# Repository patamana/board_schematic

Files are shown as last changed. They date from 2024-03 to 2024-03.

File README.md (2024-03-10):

# パタマナボード 回路図・kicadデータ
パタマナボードの回路図やkicadデータです。

## パタマナボードの概要
XIAO用キーボード基板です。<br>
XIAOは無線接続ができて便利ですが、端子数が少なく、マトリクス構造にしてもOLEDを制御するピンなどが足りなくなってしまいます。<br>
シフトレジスタの74HC165を4つ実装することで、**XIAOの3ピンで32キーの読み取りに対応**しました。<br>
I2CによるOLED制御、TRRSジャックによる左右通信、充電用のPHコネクタやスライドスイッチが実装可能です。

## シフトレジスタの概要
XIAOのD1,D2,D3ピンが74HC165のLD,CK,QHに配線されています。<br>
LDをLOWにすることでシフトレジスタにロードされ、<br>
QHからSW0のHIGE/LOWが出力されます。<br>
CKが立ち上がるたびに出力信号がSW1,SW2...とシフトされていきます。

## ピン配置
XIAOのSDA,SCLピンがOLED用の端子のSDA,SCLに配線されています。

TRRSにはXIAOのTX,RXピンとUSBからの5Vが配線されており、左右でTXとRXが逆になっているので、TRRSジャックの実装位置を変えることで、UARTでの左右通信が可能です。

XIAOの裏面の+端子をパタマナボード裏面のBAT+端子に繋げ、スライドスイッチとPHコネクタを実装し、PHコネクタにリチウムイオンポリマーバッテリーを繋げることで充電が可能です。

バッテリーの電圧を200kΩ抵抗2つの直列で分圧した電圧がXIAOのD0ピンに印加されているので、電圧値を読み取ることでバッテリー残量がわかります。

D8,D9,D10ピンは未使用なので、自由に利用できます<br><br>

詳しい利用方法は[patamana.com](https://patamana.com)を参照してください。

Arduino IDE を用いる場合は、[patamana/keybard_firmware/simple_split_keyboard](https://github.com/patamana/keyboard_firmware/tree/main/simple_split_keyboard)のコードを参考にしてください。

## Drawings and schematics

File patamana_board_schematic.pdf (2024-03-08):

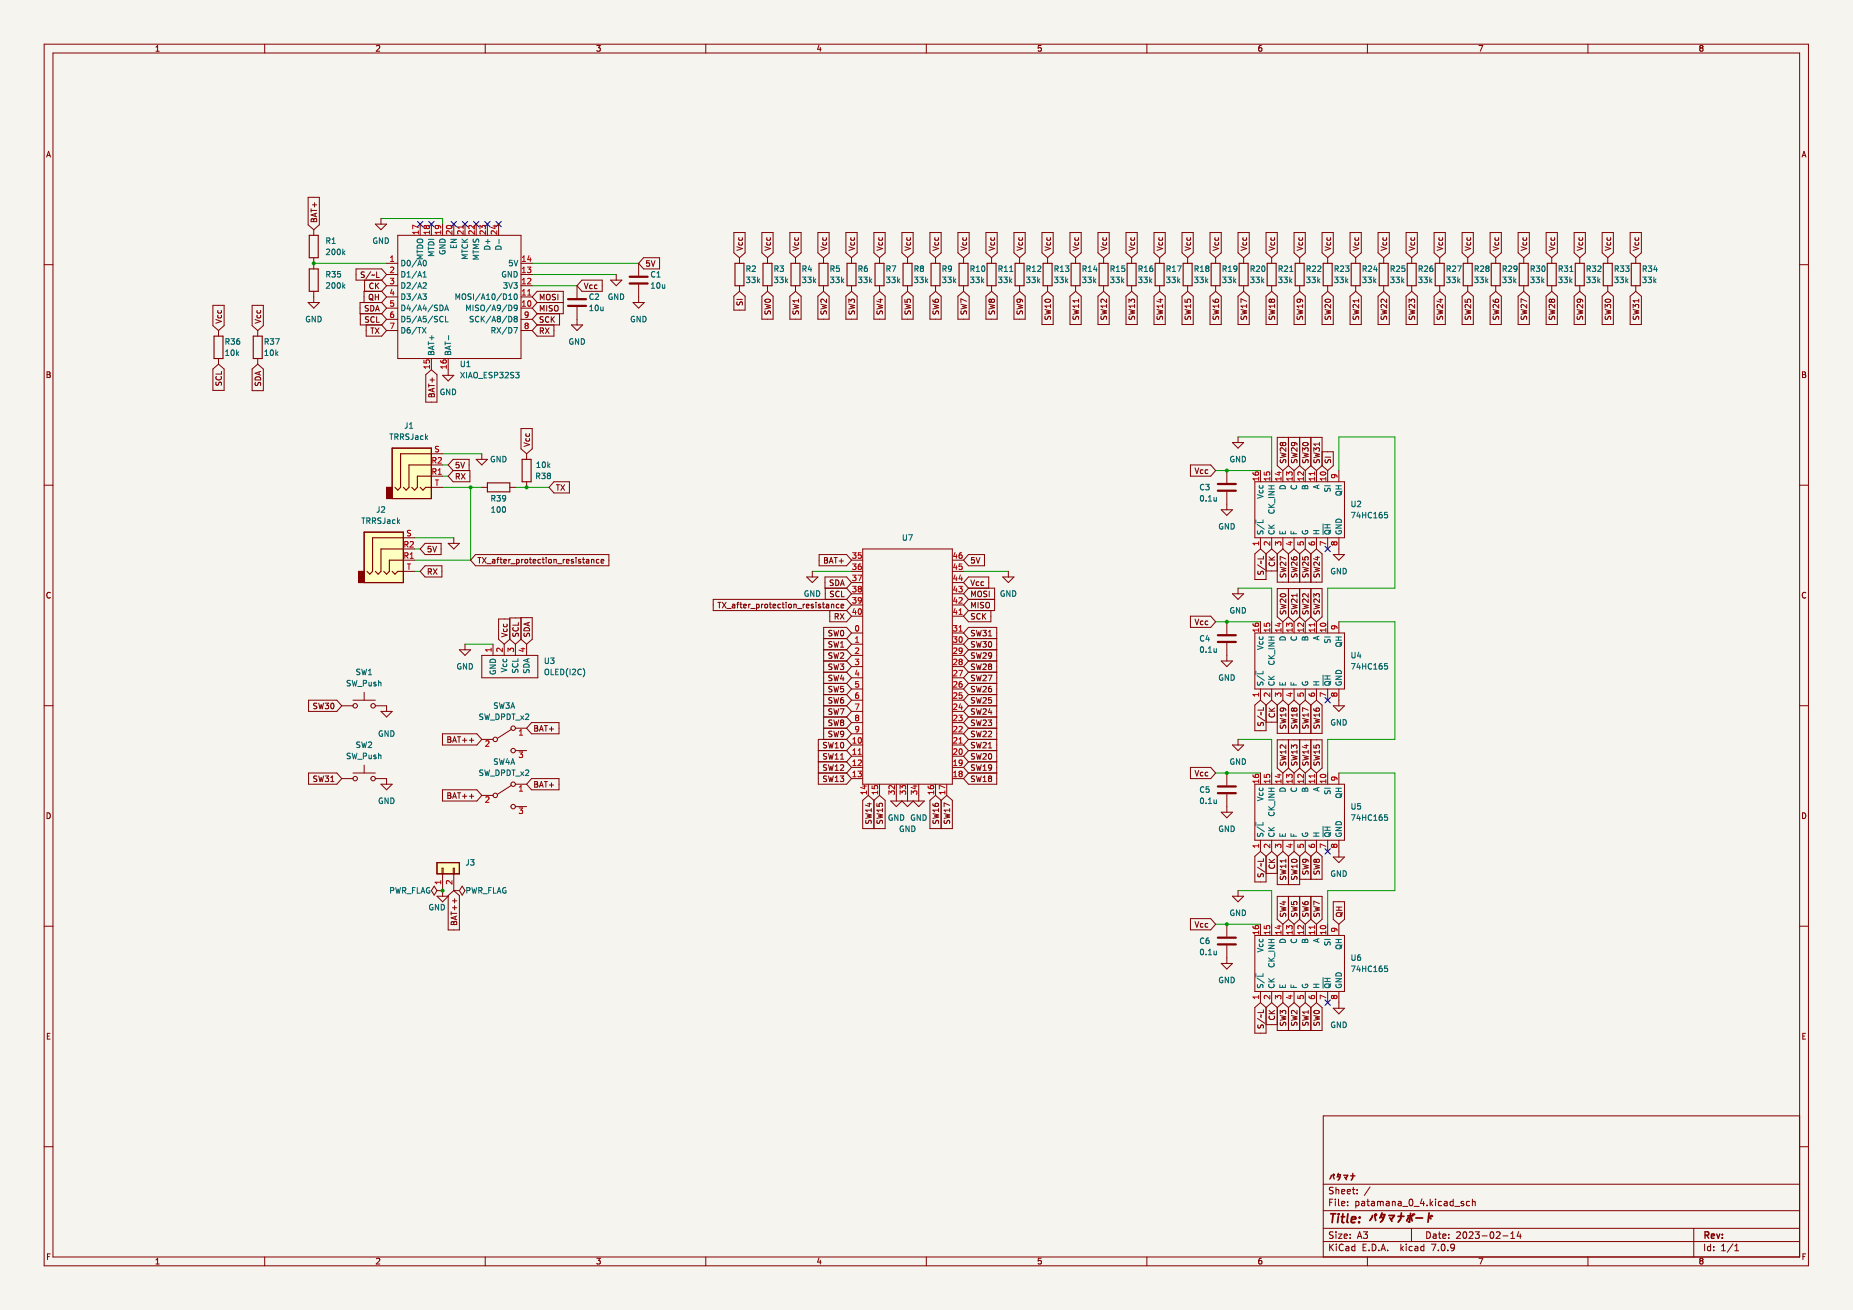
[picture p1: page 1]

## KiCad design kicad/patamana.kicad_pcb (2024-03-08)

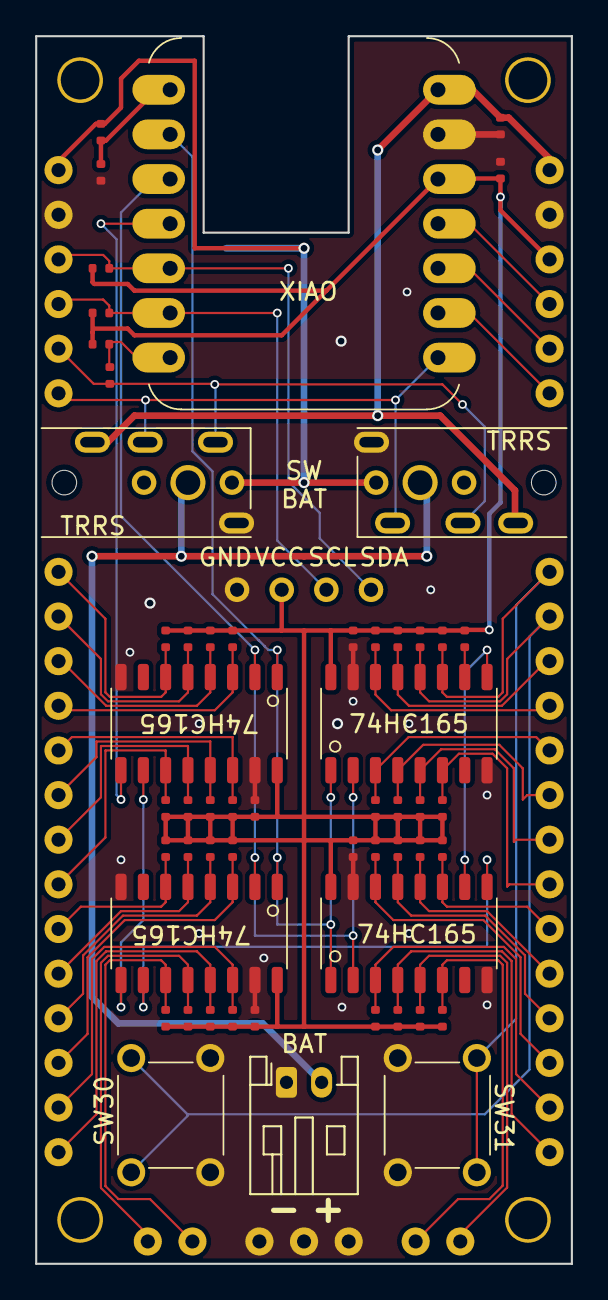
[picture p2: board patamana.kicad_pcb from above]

Board: 2 copper layers, 30.5 x 69.8 mm, 59 parts (0 on the bottom side), 53 nets.

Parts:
C1, C2: 10u; 0402
C3, C4, C5, C6: 0.1u; 0402
J1, J2: TRRSJack; MJ-4PP-9
J3: Conn_01x02; JST_PH_S2B-PH-K_1x02_P2.00mm_Horizontal
R1, R35: 200k; 0402
R2, R3, R4, R5, R6, R7, R8, R9, R10, R11, R12, R13, R14, R15, R16, R17, R18, R19, R20, R21, R22, R23, R24, R25, R26, R27, R28, R29, R30, R31, R32, R33, R34: 33k; 0402
R36, R37, R38: 10k; 0402
R39: 100; 0402
SW1, SW2: SW_Push; Tactile_Switch_TVDP01
SW3, SW4: SW_DPDT_x2; SS-12D00-G5
U1: XIAO_ESP32S3
U2, U4, U5, U6: 74HC165; SOT109-1_SO16
U3: OLED(I2C); OLED_128x64_I2C
U7: patamana_0_4_out

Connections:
5V: C1.1, J1.R2, J2.R2, U1.14 (5V), U7.46
BAT+: R1.1, SW3.1 (A), SW4.1 (A), U7.35
BAT++: J3.2, SW3.2 (B), SW4.2 (B)
CK: U1.3 (D2/A2), U2.2 (CK), U4.2 (CK), U5.2 (CK), U6.2 (CK)
GND: C1.2, C2.2, C3.2, C4.2, C5.2, C6.2, J1.S, J2.S, J3.1, R35.2, SW1.2, SW2.2, U1.13 (GND), U2.8 (GND), U2.15 (CK_INH), U3.1 (GND), U4.8 (GND), U4.15 (CK_INH), U5.8 (GND), U5.15 (CK_INH), U6.8 (GND), U6.15 (CK_INH), U7.32, U7.33, U7.34, U7.36, U7.45
MISO: U1.10 (MISO/A9/D9), U7.42
MOSI: U1.11 (MOSI/A10/D10), U7.43
unnamed: R1.2, R35.1, U1.1 (D0/A0)
unnamed: U2.9 (QH), U4.10 (SI)
unnamed: U4.9 (QH), U5.10 (SI)
unnamed: U5.9 (QH), U6.10 (SI)
QH: U1.4 (D3/A3), U6.9 (QH)
RX: J1.R1, J2.T, U1.8 (RX/D7), U7.40
SCK: U1.9 (SCK/A8/D8), U7.41
SCL: R36.2, U1.6 (D5/A5/SCL), U3.3 (SCL), U7.38
SDA: R37.2, U1.5 (D4/A4/SDA), U3.4 (SDA), U7.37
SI: R2.2, U2.10 (SI)
SW0: R3.2, U6.6 (H), U7.0
SW1: R4.2, U6.5 (G), U7.1
SW2: R5.2, U6.4 (F), U7.2
SW3: R6.2, U6.3 (E), U7.3
SW4: R7.2, U6.14 (D), U7.4
SW5: R8.2, U6.13 (C), U7.5
SW6: R9.2, U6.12 (B), U7.6
SW7: R10.2, U6.11 (A), U7.7
SW8: R11.2, U5.6 (H), U7.8
SW9: R12.2, U5.5 (G), U7.9
SW10: R13.2, U5.4 (F), U7.10
SW11: R14.2, U5.3 (E), U7.11
SW12: R15.2, U5.14 (D), U7.12
SW13: R16.2, U5.13 (C), U7.13
SW14: R17.2, U5.12 (B), U7.14
SW15: R18.2, U5.11 (A), U7.15
SW16: R19.2, U4.6 (H), U7.16
SW17: R20.2, U4.5 (G), U7.17
SW18: R21.2, U4.4 (F), U7.18
SW19: R22.2, U4.3 (E), U7.19
SW20: R23.2, U4.14 (D), U7.20
SW21: R24.2, U4.13 (C), U7.21
SW22: R25.2, U4.12 (B), U7.22
SW23: R26.2, U4.11 (A), U7.23
SW24: R27.2, U2.6 (H), U7.24
SW25: R28.2, U2.5 (G), U7.25
SW26: R29.2, U2.4 (F), U7.26
SW27: R30.2, U2.3 (E), U7.27
SW28: R31.2, U2.14 (D), U7.28
SW29: R32.2, U2.13 (C), U7.29
SW30: R33.2, SW1.1, U2.12 (B), U7.30
SW31: R34.2, SW2.1, U2.11 (A), U7.31
S/~L: U1.2 (D1/A1), U2.1 (S/~L), U4.1 (S/~L), U5.1 (S/~L), U6.1 (S/~L)
TX: R38.1, R39.2, U1.7 (D6/TX)
TX_after_protection_resistance: J1.T, J2.R1, R39.1, U7.39
Vcc: C2.1, C3.1, C4.1, C5.1, C6.1, R2.1, R3.1, R4.1, R5.1, R6.1, R7.1, R8.1, R9.1, R10.1, R11.1, R12.1, R13.1, R14.1, R15.1, R16.1, R17.1, R18.1, R19.1, R20.1, R21.1, R22.1, R23.1, R24.1, R25.1, R26.1, R27.1, R28.1, R29.1, R30.1, R31.1, R32.1, R33.1, R34.1, R36.1, R37.1, R38.2, U1.12 (3V3), U2.16 (Vcc), U3.2 (Vcc), U4.16 (Vcc), U5.16 (Vcc), U6.16 (Vcc), U7.44

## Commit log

2024-03-08 追加:patamana_board_schematic.pdf ファイルの追加
2024-03-08 追加:kicad フォルダの追加
    [patamana.kicad_pcb, patamana.kicad_sch]
2024-03-08 追加:README.md ファイルの追加
2024-03-08 修正:README.mdの修正
2024-03-08 追加:README.mdにピン配置の説明を追加
2024-03-08 整理:名前の整理
    [patamana.kicad_pcb, patamana.kicad_sch]
